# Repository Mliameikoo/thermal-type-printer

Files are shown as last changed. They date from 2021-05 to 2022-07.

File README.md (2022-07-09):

# ThermalTypePrinter

#### 介绍
2021年5月开始的热敏打字机项目，根据开源项目二次开发而来，通过上位机可以进行任意字体、长度的打印。上位机带有完整的参数显示与配置功能。

#### 软件架构
软件架构说明：STM32F103C8 + FreeRTOS / C#上位机 + 串口协议控制

#### 图片展示
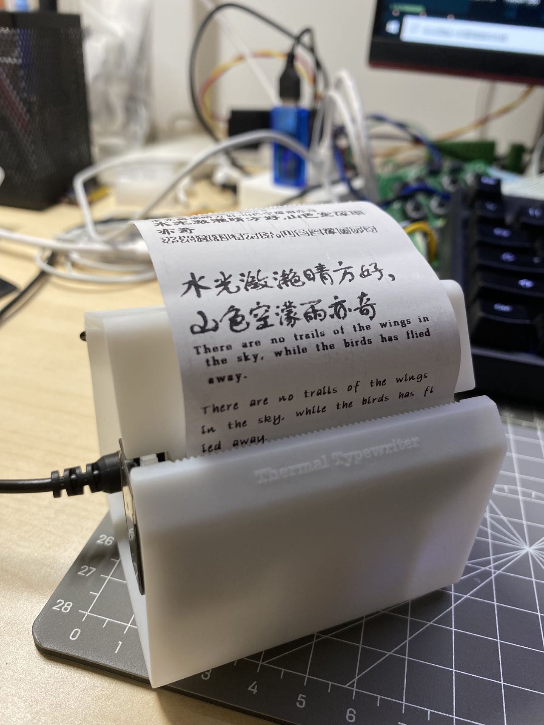
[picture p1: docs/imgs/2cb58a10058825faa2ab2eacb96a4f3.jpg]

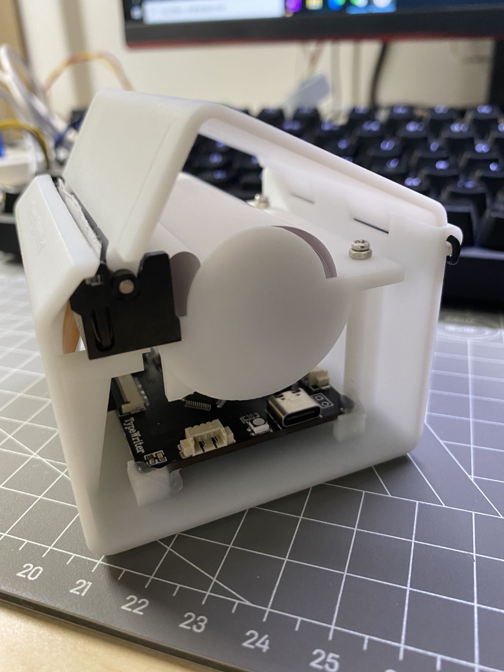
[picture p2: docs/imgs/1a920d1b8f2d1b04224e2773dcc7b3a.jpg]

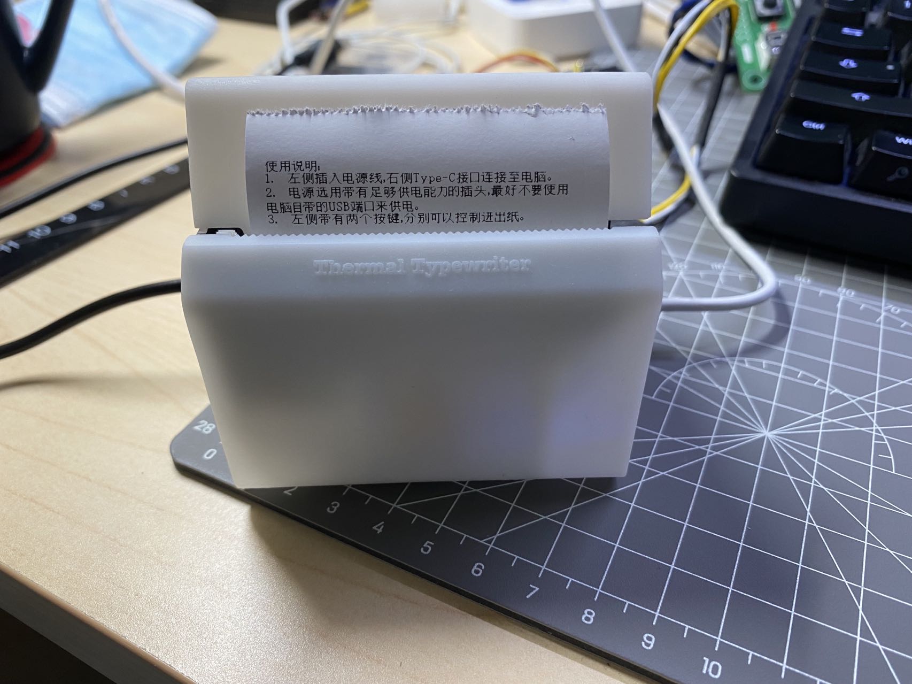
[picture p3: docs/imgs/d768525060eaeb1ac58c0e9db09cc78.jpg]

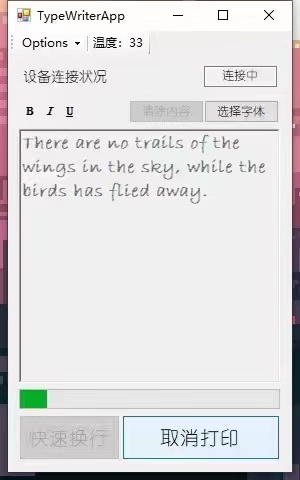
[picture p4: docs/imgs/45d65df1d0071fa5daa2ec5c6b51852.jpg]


#### 使用说明

1.  板卡使用USB-虚拟串口，连接至电脑后上位机可自动扫描到设备。
2.  热敏打印头长时间工作可能会过热，上位机带有打印头温度监测功能。
3.  上位机Options窗口中可以对打印偏移参数进行配置，以适应不同打印头、纸张的安装情况。
4.  带有打字机模式，可在上位机Options窗口中进行模式切换。

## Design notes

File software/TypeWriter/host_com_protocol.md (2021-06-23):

## Host Computer Communication Protocol 
> version 1.0
> date: 2021/06/15

#### 1. Format  
|frame_head|valid_length_high8bits|valid_length_low8bits|command|valid_data|sum_check|frame_tail|
|:-:|:-:|:-:|:-:|:-:|:-:|:-:|
|0xF5|x1|x2|x3|x4[...]|x3|0x5F|  
#### 2. Valid Length High-8bits - x1  
The High-8bits of length of valid_data.  
#### 3. Valid Length Low-8bits - x2  
The Low-8bits of length of valid_data.  
#### 3. Command List - x3  
|command|x1|
|:-:|:-:|
|single_word_write|0x01|
|paragraph_write|0x02|  
|image_write|0x03|  
|special_order|0x04|  
#### 4. Valid Data - x4[...]  
Should limit as the APP_RX_DATA_SIZE.  
#### 5. Sum Check - x5  
One byte sum of (command + valid_data).

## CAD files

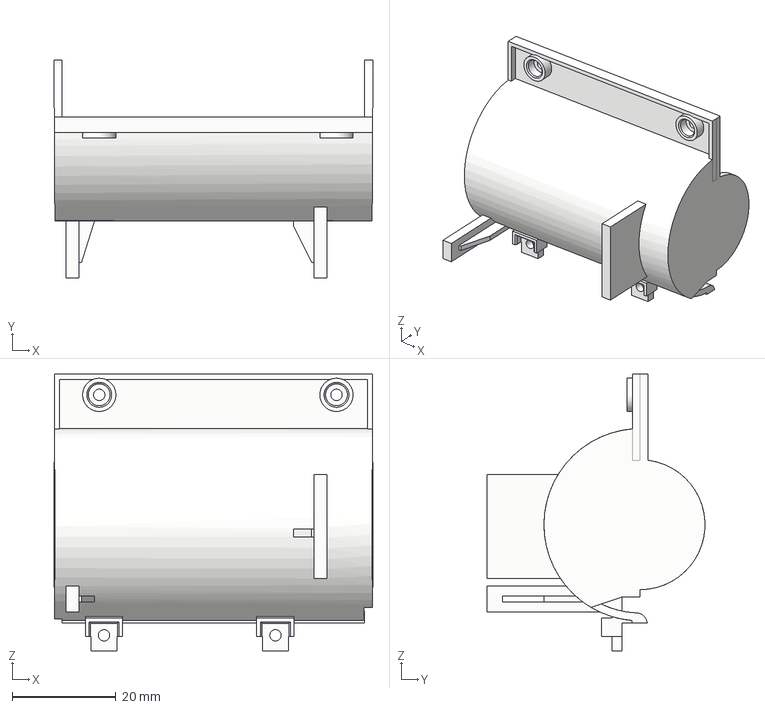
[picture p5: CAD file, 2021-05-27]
enclosure/部件-纸仓.step
61.4 x 41.9 x 53.3 mm

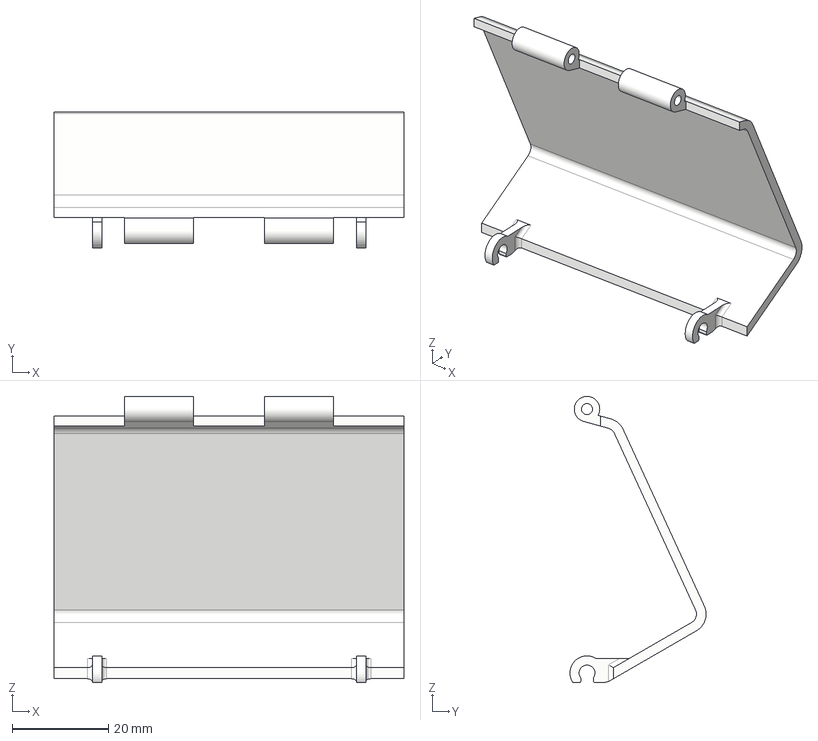
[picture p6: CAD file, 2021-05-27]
enclosure/部件-上盖.step
72.7 x 28.3 x 59.5 mm

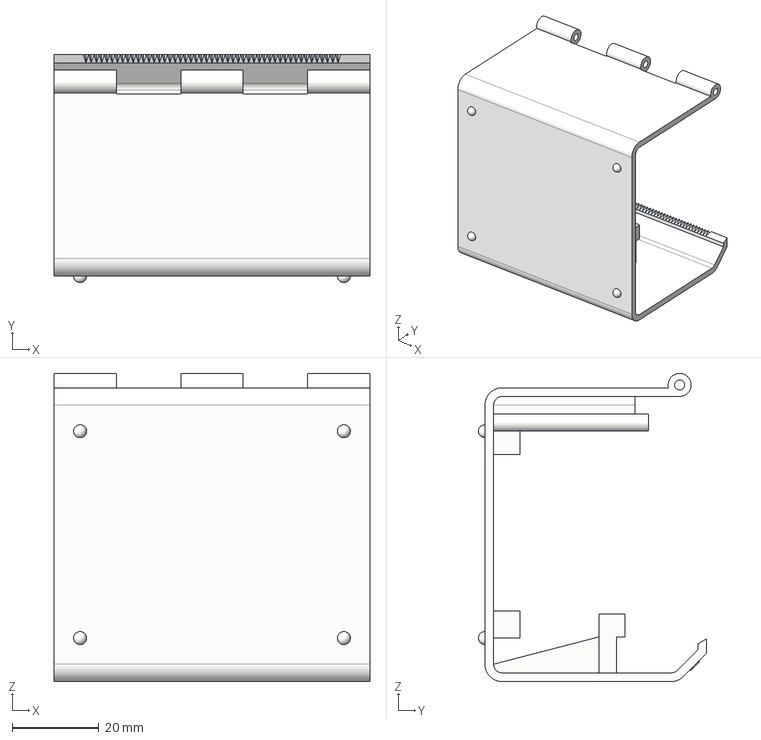
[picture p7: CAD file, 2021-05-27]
enclosure/部件-下盖.step
72.7 x 52.5 x 70.9 mm

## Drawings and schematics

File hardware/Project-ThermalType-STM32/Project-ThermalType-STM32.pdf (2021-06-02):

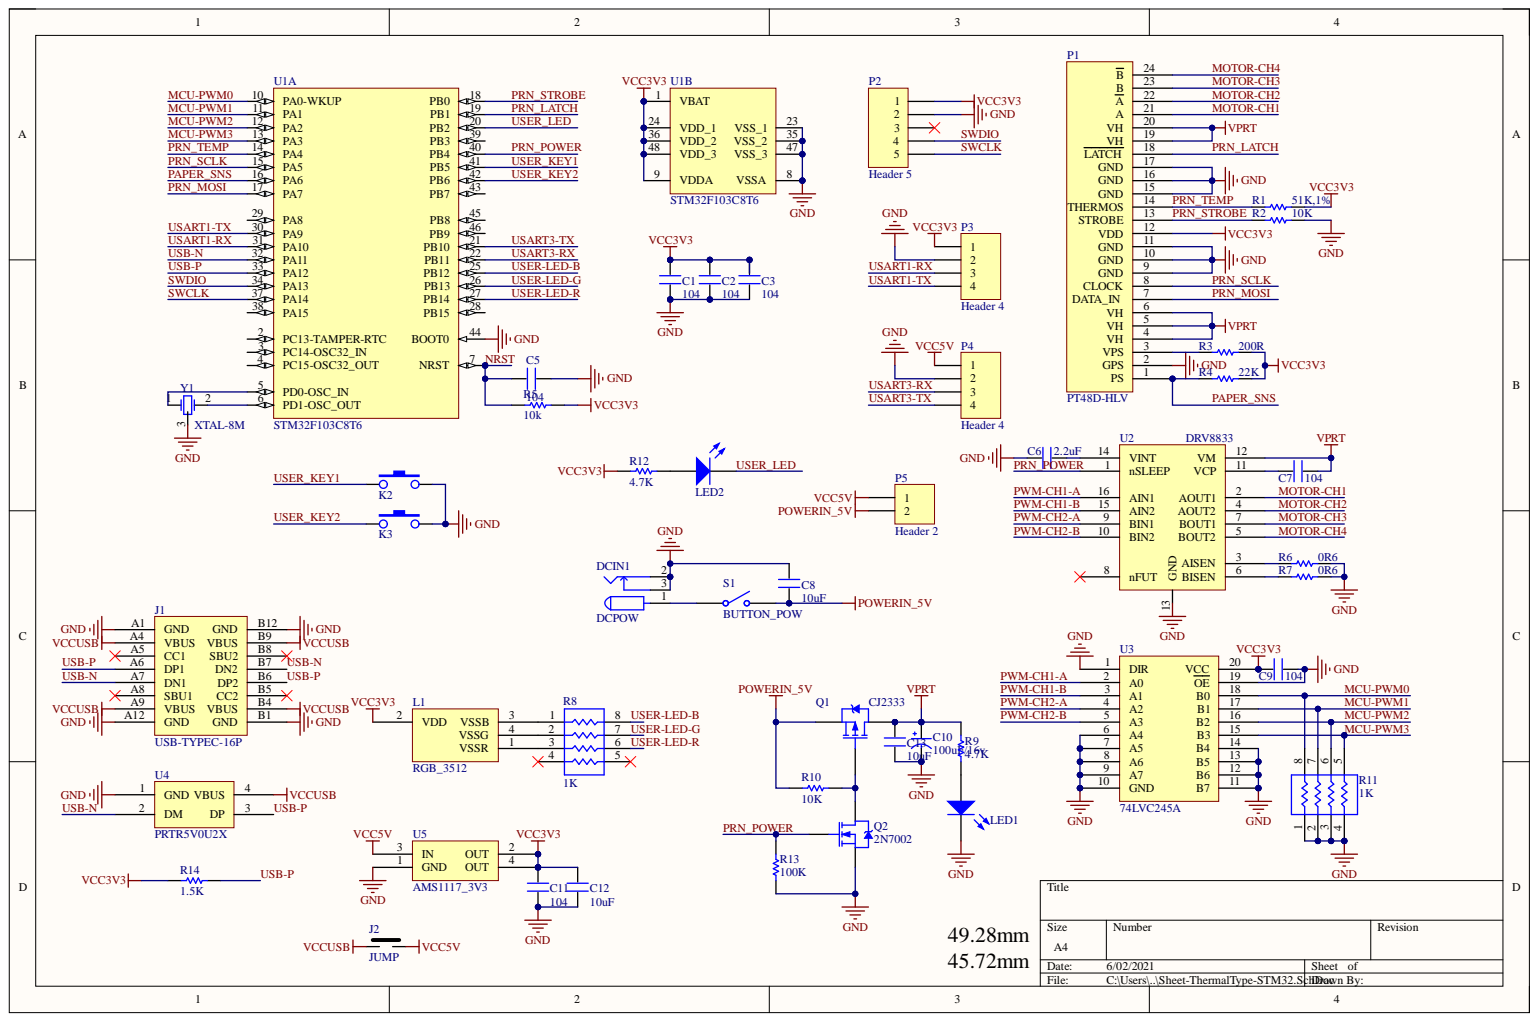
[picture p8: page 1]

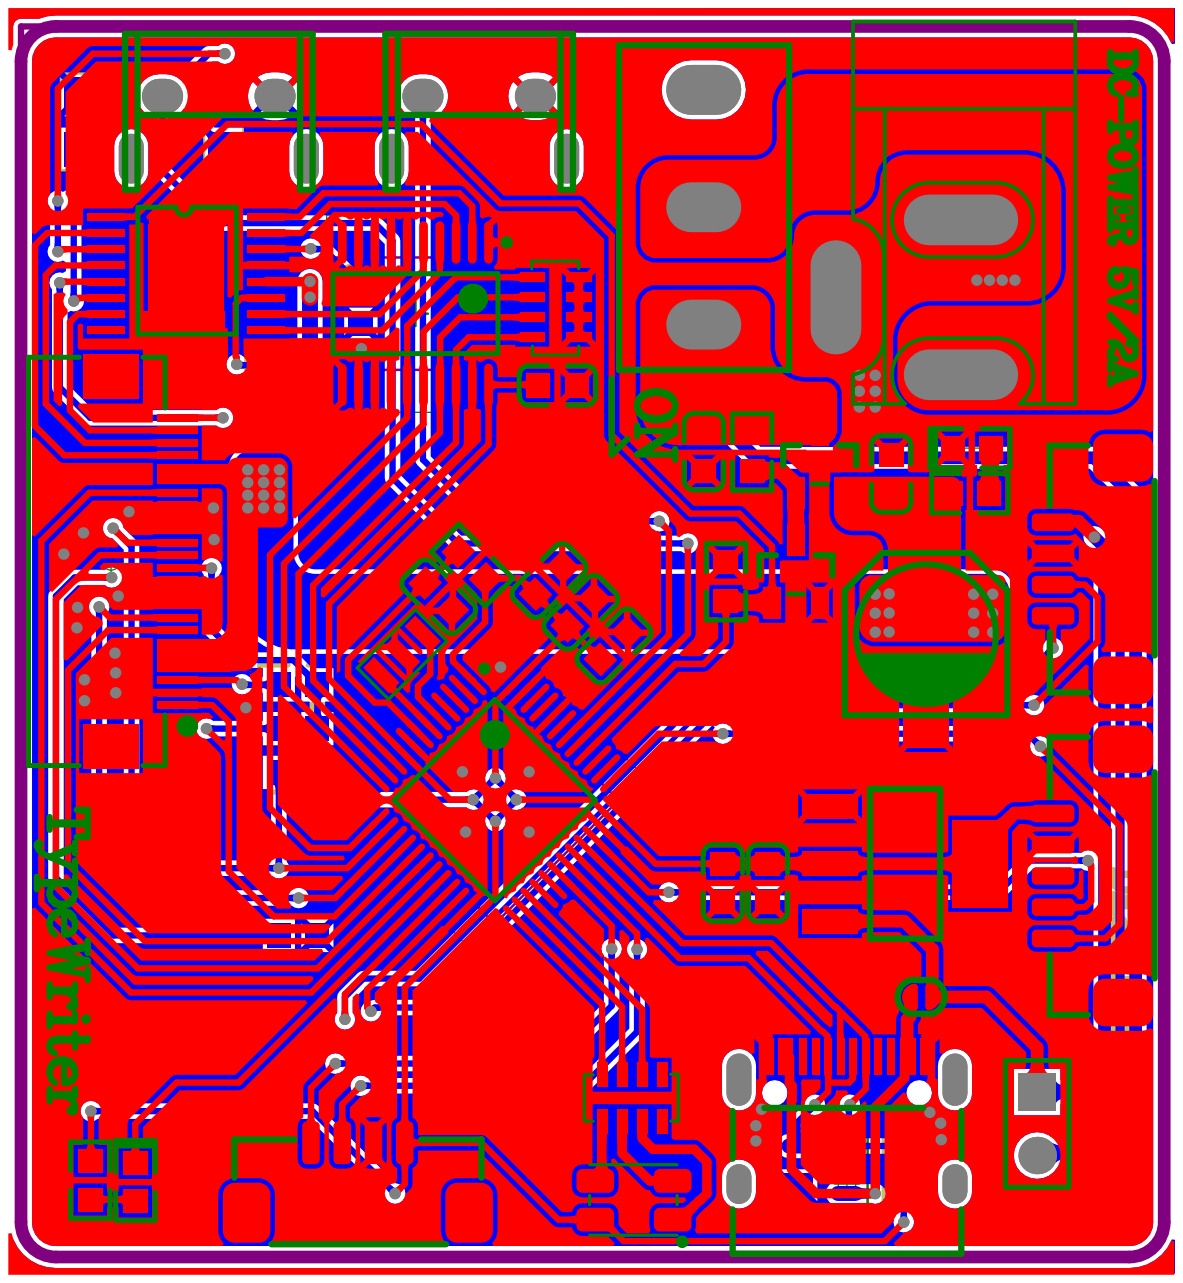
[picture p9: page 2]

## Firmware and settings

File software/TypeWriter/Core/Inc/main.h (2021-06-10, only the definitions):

#define MOTOR_IN1_Pin GPIO_PIN_0
#define MOTOR_IN1_GPIO_Port GPIOA
#define MOTOR_IN2_Pin GPIO_PIN_1
#define MOTOR_IN2_GPIO_Port GPIOA
#define MOTOR_IN3_Pin GPIO_PIN_2
#define MOTOR_IN3_GPIO_Port GPIOA
#define MOTOR_IN4_Pin GPIO_PIN_3
#define MOTOR_IN4_GPIO_Port GPIOA
#define PRN_SNS_Pin GPIO_PIN_6
#define PRN_SNS_GPIO_Port GPIOA
#define PRN_STROBE_Pin GPIO_PIN_0
#define PRN_STROBE_GPIO_Port GPIOB
#define PRN_LATCH_Pin GPIO_PIN_1
#define PRN_LATCH_GPIO_Port GPIOB
#define USER_LED_Pin GPIO_PIN_2
#define USER_LED_GPIO_Port GPIOB
#define USER_LED_B_Pin GPIO_PIN_12
#define USER_LED_B_GPIO_Port GPIOB
#define USER_LED_G_Pin GPIO_PIN_13
#define USER_LED_G_GPIO_Port GPIOB
#define USER_LED_R_Pin GPIO_PIN_14
#define USER_LED_R_GPIO_Port GPIOB
#define PRN_POWER_Pin GPIO_PIN_4
#define PRN_POWER_GPIO_Port GPIOB
#define USER_KEY1_Pin GPIO_PIN_5
#define USER_KEY1_GPIO_Port GPIOB
#define USER_KEY2_Pin GPIO_PIN_6
#define USER_KEY2_GPIO_Port GPIOB

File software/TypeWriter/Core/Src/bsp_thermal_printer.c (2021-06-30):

/* Includes ------------------------------------------------------------------*/
#include "bsp_thermal_printer.h"
/* Private includes ----------------------------------------------------------*/
#include "main.h"
#include "spi.h"
#include "user_app.h"
#include "font_thermal_printer.h"
#include <stdarg.h>

#include "FreeRTOS.h"
#include "cmsis_os.h"
/* Private define ------------------------------------------------------------*/
#define PRINTER_ROW_WIDTH 384 // 2'inch thermal-printer-head, 384 points / 48 byte
// Default font size is too small to read.
// Set scale to 2 for normal use. Set to 3 for demonstration.
#define PRINTER_TEXT_SCALE 2
#define PRINTER_OFF_HEIGHT 40 // 打印完额外滚动的高度，用于方便观看打印效果

#define PRINTER_POWER_ON() HAL_GPIO_WritePin(PRN_POWER_GPIO_Port, PRN_POWER_Pin, GPIO_PIN_SET)
#define PRINTER_POWER_OFF() HAL_GPIO_WritePin(PRN_POWER_GPIO_Port, PRN_POWER_Pin, GPIO_PIN_RESET)
#define PRINTER_HEATING_ON() HAL_GPIO_WritePin(PRN_STROBE_GPIO_Port, PRN_STROBE_Pin, GPIO_PIN_SET)
#define PRINTER_HEATING_OFF() HAL_GPIO_WritePin(PRN_STROBE_GPIO_Port, PRN_STROBE_Pin, GPIO_PIN_RESET)
#define PRINTER_LATCH_ON() HAL_GPIO_WritePin(PRN_LATCH_GPIO_Port, PRN_LATCH_Pin, GPIO_PIN_SET)
#define PRINTER_LATCH_OFF() HAL_GPIO_WritePin(PRN_LATCH_GPIO_Port, PRN_LATCH_Pin, GPIO_PIN_RESET)
#define PRINTER_PAPER_EXIST_READ() HAL_GPIO_ReadPin(PRN_SNS_GPIO_Port, PRN_SNS_Pin) // 缺纸输出高电平

#define my_min(a, b) ((a > b) ? b : a)

//#define DEBUG_DISABLE_HEATING   // 调试模式下禁止热敏打印机加热

/* Private variables ---------------------------------------------------------*/
const uint8_t MOTOR_PHASES[][4] = {
    {1, 0, 0, 0},
    {1, 0, 0, 1},
    {0, 0, 0, 1},
    {0, 1, 0, 1},
    {0, 1, 0, 0},
    {0, 1, 1, 0},
    {0, 0, 1, 0},
    {1, 0, 1, 0},
    {0, 0, 0, 0} /* idle */
};
// Backspace glyph (dotted block)
static uint8_t font_backspace_char_raster[FONT_CHAR_HEIGHT] = {
    0xAA, 0x55, 0xAA, 0x55, 0xAA, 0x55, 0xAA, 0x55, 0xAA, 0x55, 0xAA, 0x55, 0xAA, 0x55, 0xAA, 0x55, /*backspace*/
};
struct printerInfoDef printerInfo;
/* Private macro -------------------------------------------------------------*/

static int8_t text_limit_length(const uint8_t start_nums, const uint8_t write_nums, uint8_t *single_line_char_nums);
static int8_t text_handle_illegal_character(uint8_t *write_buf, const uint8_t single_line_char_nums, uint8_t *(*rasters_pointer));
static int8_t text_set_alignment(const enum textSetAlignDef align, const uint8_t single_line_char_nums, uint16_t *start_x_pos);
static int8_t text_print_pixel_row(uint8_t *(*rasters_pointer), const uint8_t single_line_char_nums, const uint16_t start_x_pos);

static void printer_spi_send_data(uint8_t *data);
static int8_t printer_feed_paper_with_lines(int16_t lines_nums);
static int8_t printer_print_single_pixel_line(uint8_t *data);

static int8_t motor_set_idle(void);
static void motor_set_phases(const uint8_t phases[4]);
static void motor_single_step(uint8_t direction);

static int8_t printer_feed_paper_with_1bit_lines(int16_t lines_nums);

/* Private user code ---------------------------------------------------------*/

/**
  * @brief  thermal printer init
  */
int8_t printer_init(void)
{
  int8_t retval = 0;
  // init param
  printerInfo.scale = 1; // 缩放值
  printerInfo.xpos_char_max_nums = PRINTER_ROW_WIDTH / 8 / printerInfo.scale;
  printerInfo.line_height = 16 * printerInfo.scale;
  printerInfo.height_offset = -2; // Y轴偏移
  // init device
  PRINTER_HEATING_OFF();
  PRINTER_LATCH_OFF();
  uint8_t empty_array[PRINTER_ROW_WIDTH / 8] = {0};
  HAL_SPI_Transmit(&hspi1, empty_array, PRINTER_ROW_WIDTH / 8, 5);
  PRINTER_LATCH_ON();
  printer_new_lines(printerInfo.line_height, 2);
  motor_set_idle();
  return retval;
}

/**
  * @brief  update motor-phases in tim4_irq.  
  *         run interval as 500us/0.5ms 
  */
void motor_phases_update_loop(void)
{
  if (printerInfo.motor_run_cnt != 0)
  {
    motor_single_step(printerInfo.motor_run_cnt > 0);
    printerInfo.motor_run_cnt += (printerInfo.motor_run_cnt > 0) ? (-1) : (1);
  }
}

/**
  * @brief  设置打印缩放比例
  * @param  scale: 缩放倍数
  * @retval 0:success, 1:非法参数
  */
int8_t printer_change_char_scale(uint8_t scale)
{
  if (scale > 3)
  {
    return -1;
  }
  printerInfo.scale = scale;
  printerInfo.xpos_char_max_nums = PRINTER_ROW_WIDTH / 8 / printerInfo.scale;
  return 0;
}

/**
  * @brief  打印图像
  * @param  width: 图像的真实宽度(bit)
  * @param  height: 图像的真实高度(bit)
  * @param  buf:  图像数据(列行式，先列再行，纸面上字节低位在字节高位的上方)，buf.length / width >= height
  * @retval 0:success, 1:缺纸
  */
int8_t printer_write_image_text(const struct imageTransmitInfoDef image)
{
  int8_t retval = 0;
  uint8_t single_line_pixel_write_buf[PRINTER_ROW_WIDTH / 8] = {0};

  static int16_t last_feed_pixel_lines = 0;

  PRINTER_POWER_ON();

  // 自动换行
  uint8_t next_lines = 0;
  if ((printerInfo.xpos_pixel + image.width * printerInfo.scale) > PRINTER_ROW_WIDTH)
  {
    next_lines = 1;
    printerInfo.xpos_pixel = 0;
  }
  // 回纸，继续打印
  printer_feed_paper_with_lines(-1 * last_feed_pixel_lines - PRINTER_OFF_HEIGHT + next_lines * last_feed_pixel_lines);
  printer_feed_paper_with_1bit_lines(printerInfo.height_offset);
  // motor_set_idle();

  // 将图像数据转置方向，并打印
  last_feed_pixel_lines = 0;
  for (uint8_t page = 0; page < image.buf.length / image.width; page++)
  {
    for (uint8_t pos = 0; pos < 8; pos++)
    {
      if (pos + page * 8 >= image.height)
      {
        break;
      }
      memset(single_line_pixel_write_buf, 0, sizeof(single_line_pixel_write_buf) / sizeof(uint8_t));
      for (uint16_t i = 0; i < image.width; i++)
      {
        uint8_t val = image.buf.val[i + page * image.width];
        if ((val & (1 << pos)) != 0)
        {
          // // 不带横向缩放写入
          // single_line_pixel_write_buf[(printerInfo.xpos_pixel + i) / 8] |= 1 << (7 - ((printerInfo.xpos_pixel + i) % 8));
          // 带横向缩放写入
          for (uint16_t j = i * printerInfo.scale; j < (i + 1) * printerInfo.scale; j++)
          {
            single_line_pixel_write_buf[((printerInfo.xpos_pixel + j) / 8)] |= 1 << (7 - ((printerInfo.xpos_pixel + j) % 8));
          }
        }
      }
      for (uint8_t j = 0; j < printerInfo.scale; j++)
      {
        retval = printer_print_single_pixel_line(single_line_pixel_write_buf);
        if (retval)
        {
          break;
        }
        else
        {
          last_feed_pixel_lines += 1;
        }
      }
    }
  }
  // last_feed_pixel_lines += image.height;
  printerInfo.xpos_pixel += image.width * printerInfo.scale;

  printer_feed_paper_with_lines(PRINTER_OFF_HEIGHT);
  motor_set_idle();

  PRINTER_POWER_OFF();

  return retval;
}
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

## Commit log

2021-05-30 删除文件 hardware/Project-ThermalType-STM32/History
2021-05-30 删除文件 hardware/Project-ThermalType-STM32/__Previews
2021-05-30 删除文件 hardware/Project-ThermalType-STM32/Project Logs for Project-ThermalType-STM32
2021-05-31 210531 hardware
    [Sheet-ThermalType-STM32.SchDoc]
2021-06-01 finish pcb
    [Sheet-ThermalType-STM32.SchDoc]
2021-06-02 update pdf
    [Project-ThermalType-STM32.PrjPcb]
2021-06-14 210613 software printer_text down
2021-06-24 210624 software-update： 1. 修复了字体比特位图的上方截断现象，并对其进行左右多余部分截断。 2. 增加上位机的文本格式快捷设置（加粗倾斜等） 3. 整理了上位机源码。 4. 增加了richTextBox中的右键功能栏。 5. 增加了上位机的文本框清除按钮。 6. 增加了上位机的快速换行按钮功能模块。
    [TypeWriter.ioc, bsp_thermal_printer.c, user_app.c]
2021-06-26 2021/06/25 software-update 1. 修改了MCU与上位机之间的单次传输应答机制：以帧包的形式传输应答。至此，MCU与上位机之间的双向通信皆以完整数据帧打包发送。 2. 上位机线程内已加入委托机制，可进行仿真了。
    [温度电阻.xlsx]
2022-07-09 新建 imgs

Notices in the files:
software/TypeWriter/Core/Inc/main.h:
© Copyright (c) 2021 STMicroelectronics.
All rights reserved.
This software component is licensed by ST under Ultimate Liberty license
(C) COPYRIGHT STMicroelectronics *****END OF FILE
